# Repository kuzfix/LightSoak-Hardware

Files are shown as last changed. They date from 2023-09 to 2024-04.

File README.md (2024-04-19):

# LightSoak Hardware
This repository contains hardware design files for LightSoak project, developed in scope of my Master's thesis. For Firmware, quick start quide and a basic hardware description, see https://github.com/kuzfix/LightSoakFW-STM. For Python data logger, see https://github.com/kuzfix/LightSoakFW-Python.

LightSoak hardware can be used standalone via a Command Line Interface over USB or with a Python data logger to implement complex measurement sequences. See quick start quide at https://github.com/kuzfix/LightSoakFW-STM for more information.

## Hardware specs

### Voltage measurement channels
- Measurement range: **0-1.5V**
- ADC resolution: **12bit (STM32G4 integrated)**
- Sample rate: **100kHz**
- Differential input resistance: **3.3MOhm +- 10% (1GOhm +- 10% if input buffer board is used)**
- Noise performance: *TBD*. Use *getnoise* CLI command to evaluate.
    - *Note: Noise performance can be improved significantly by usage of the input buffer board*
- Over-range protection: **None**
- Accuracy: **+-(0.25% of measurement + 0.75mV)**

#### Voltage accuracy report
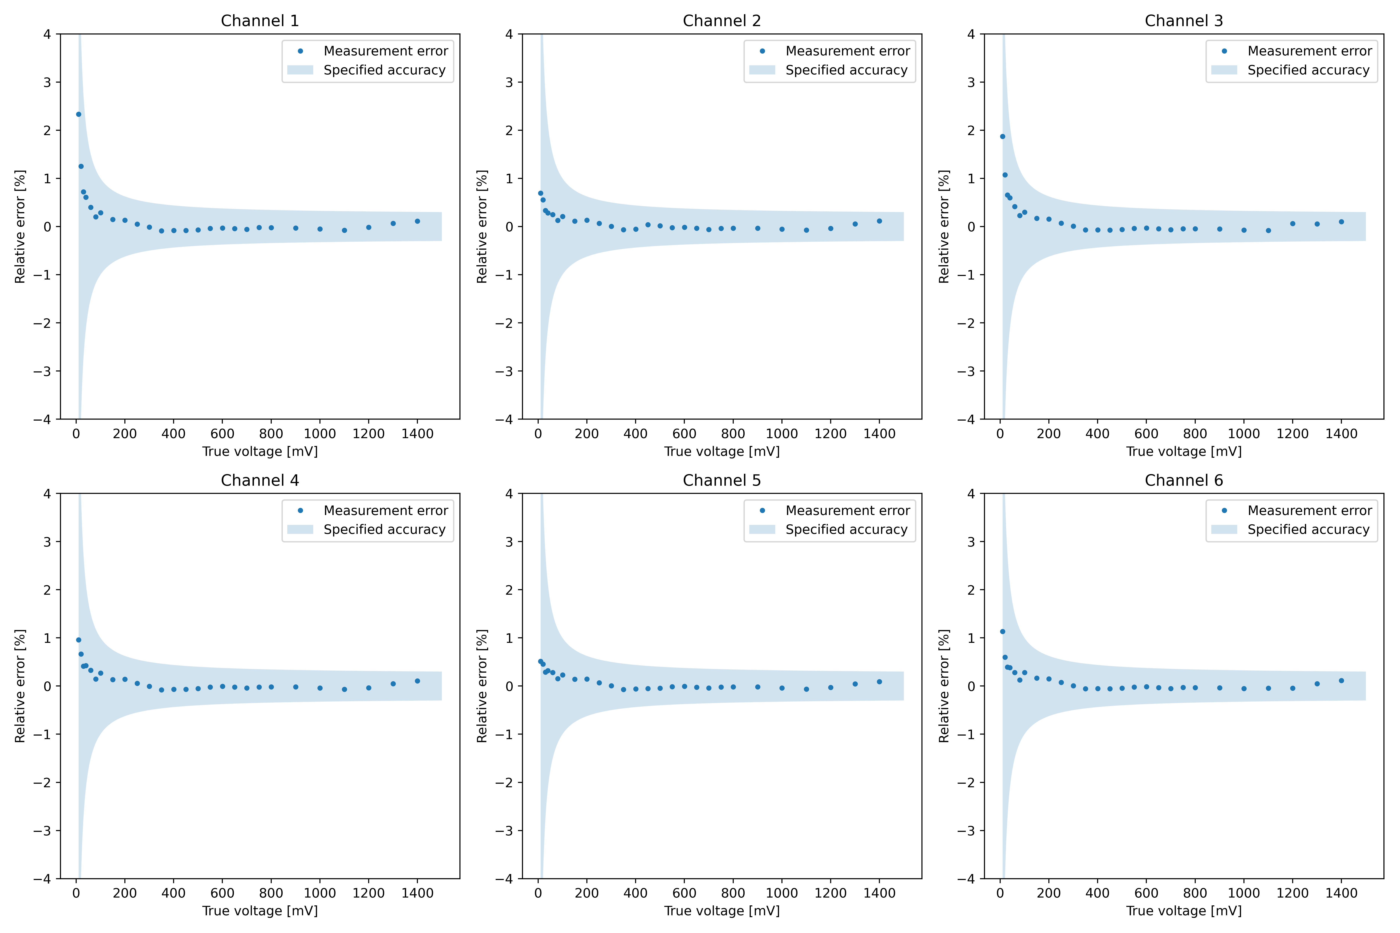
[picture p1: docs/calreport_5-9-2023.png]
Accuracy report:

- Calibration date: 5.9.2023
- Calibration equipment:
    - Keithly 237 (ULFE: 037296)
    - Agilent 34401A (ULFE: FE24)
- Sample averaging: 2000 (20ms averaging time)

### Current measurement channels
- Measurement ranges:
    - 1X: *up to 4700uA*
    - 10X: *up to 400uA*
    - 100X: *up to 40uA*
    - 1000X: *up to 4uA*
- ADC resolution: **12bit (STM32G4 integrated)**
- Sample rate: **100kHz** (simultaneous sampling with voltage channels)
- Noise performance: *TBD*. Use *getnoise* CLI command to evaluate.
- Over-range protection: **None**
- Accuracy: **+-(0.85% of measurement + 0.25uA)**
    - *Note: With shunt range optimization, higher accuracy can be reached. This is accuracy through the whole range including range switching.*
    - *Note: If the input buffer board is not used, voltage measurement circuitry loads the DUT with about 3.3Mohm. While measuring very small currents, this can cause a discrepancy between the measured and actual DUT current.

#### Current accuracy report
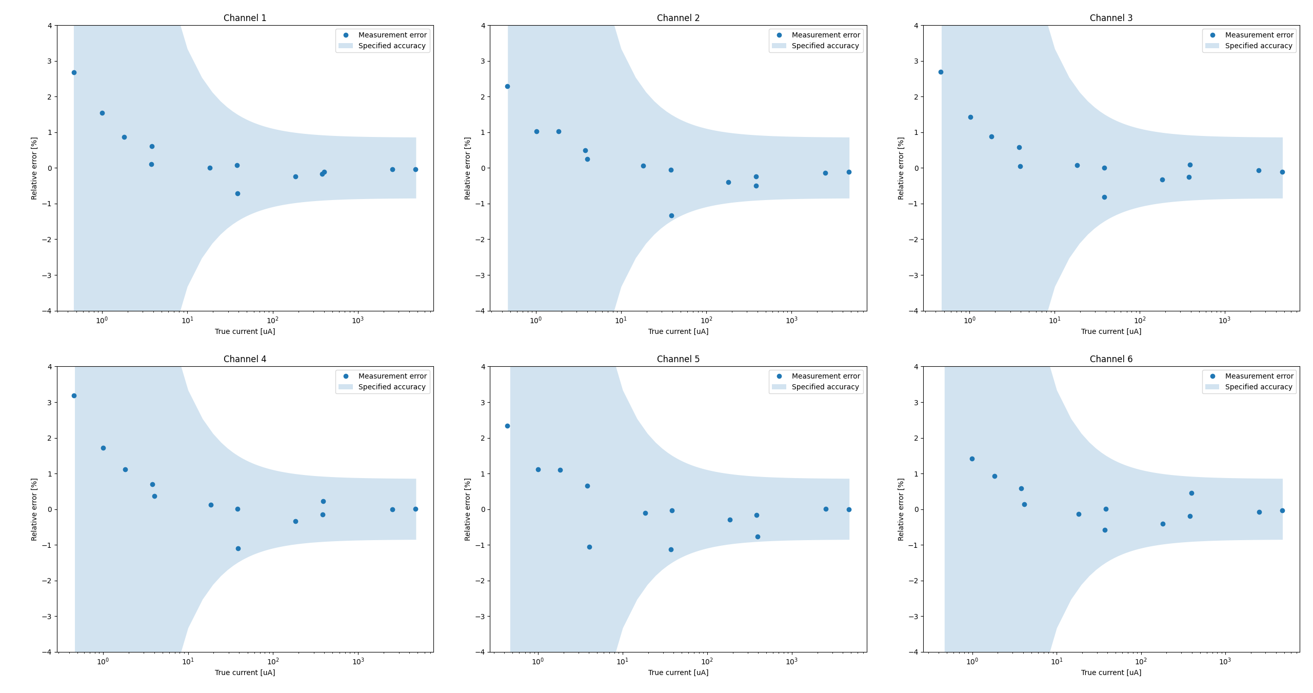
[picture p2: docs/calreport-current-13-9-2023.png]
Accuracy report:

- Calibration date: 13.9.2023
- Calibration equipment:
    - BM789
- Sample averaging: 2000 (20ms averaging time)

### Temperature control
- Handled by a TEC-1091 module mounted to the main board. See https://www.meerstetter.ch/products/tec-controllers/tec-1091 for specs.
- For continous max-power operation of temperature control, additional cooling is recomended for the power supply and TEC module section.

### Illumination
- Light output stbility: **+-1% (With LED temperature compensation)**
- Constant current range: **50mA to 1.4A**
    - *Note: Lower currents are possible with reduced transient performance*
- Settling time: **100uS to steady state, over current range**
    - *Note: Settling time is significantly shorter for higher currents. *
- 1 sun equivalent illumination (1000W/m^2): approximately 10 cm from LED at 1A (should be callibrated in-situ if accuracy is needed)
- See https://downloads.cree-led.com/files/ds/x/XLamp-CXA2530.pdf for LED specs
- Expected temperature rise of the heatsink is 10K at full power

### Power supply requirements
- **42V 2.5A DC** on input terminals to support all functionality.
- 5V 1A USB supply only (*VBUS-PWR* jumper installed): Analog functions work, performance may be degraded.

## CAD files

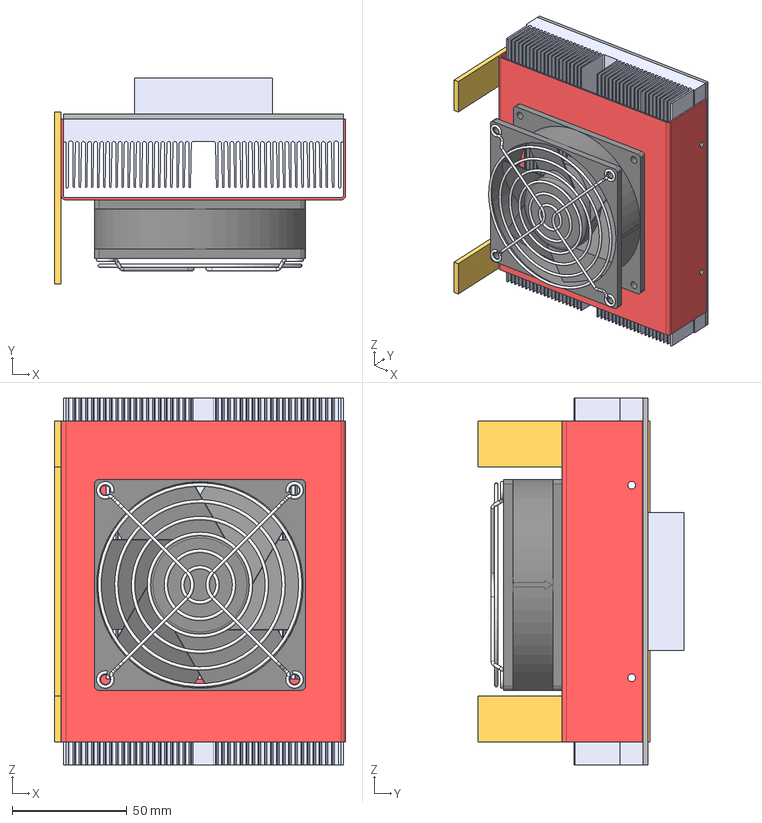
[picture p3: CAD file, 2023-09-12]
3D/mnt-bt-v2.step
127.0 x 89.6 x 160.0 mm

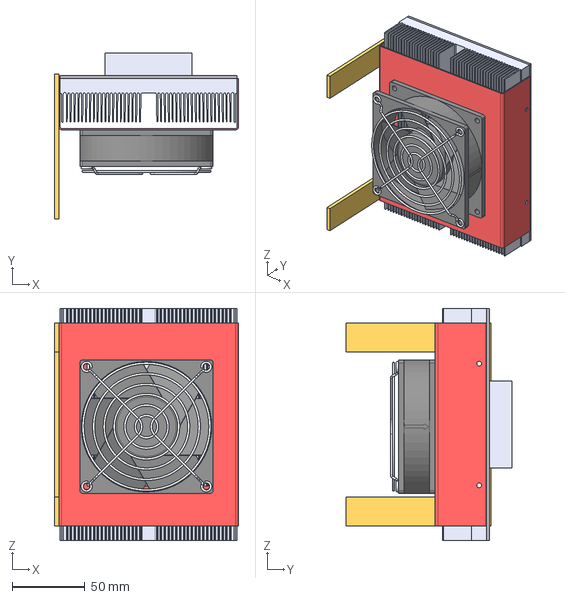
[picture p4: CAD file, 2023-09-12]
3D/mnt-btm-part-withfeet.step
127.0 x 114.6 x 160.0 mm

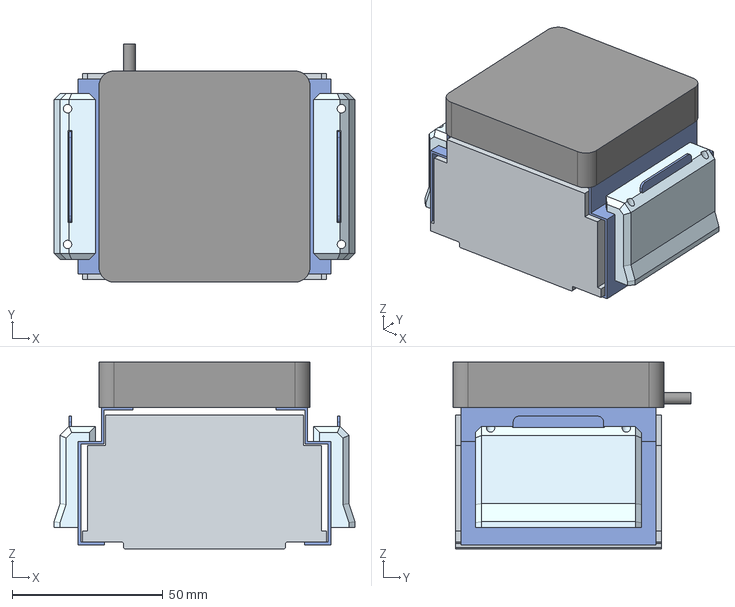
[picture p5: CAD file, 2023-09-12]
3D/LED-heatsink-withmnt.step
99.8 x 79.0 x 61.9 mm

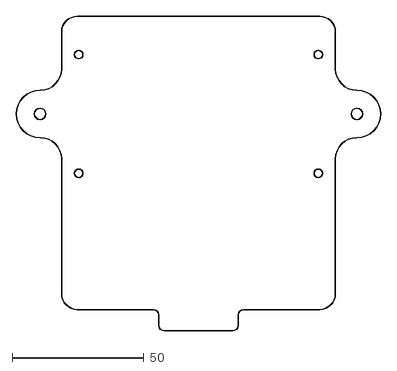
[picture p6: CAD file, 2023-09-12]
3D/LEDholder-pcb-shape-v1.dxf
138.0 x 119.2

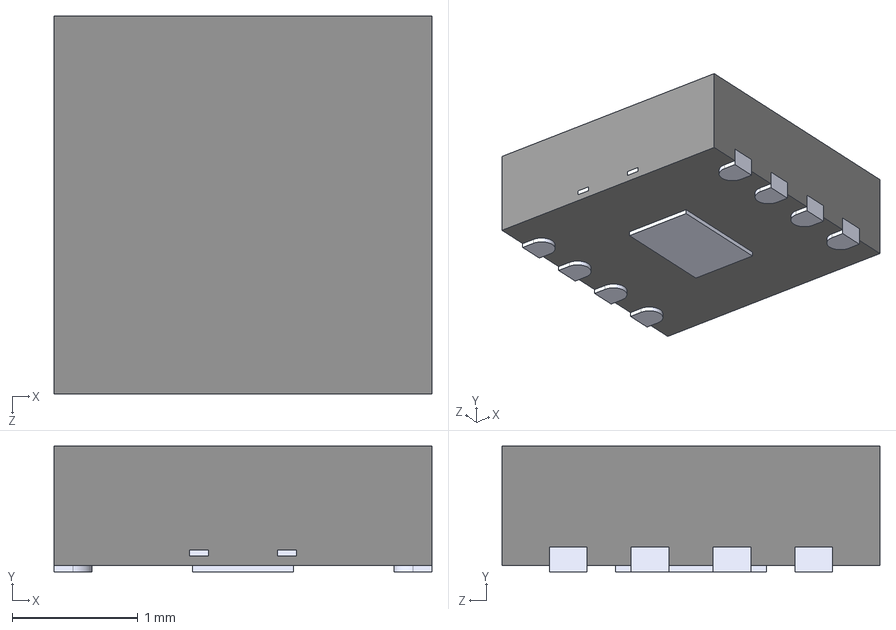
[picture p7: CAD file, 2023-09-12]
lightSoakV1-InAmp-piggyback/lightSoakV1-InAmp-piggyback/MCP14700-E_MF.STEP
3.00 x 1.00 x 3.00 mm

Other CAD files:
lightSoakV1-illumination/V1-PCB-illumination.DXF

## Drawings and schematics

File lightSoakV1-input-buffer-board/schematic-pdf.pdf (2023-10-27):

## Inline DUT unity gain buffer amplifier with extra high input impedance

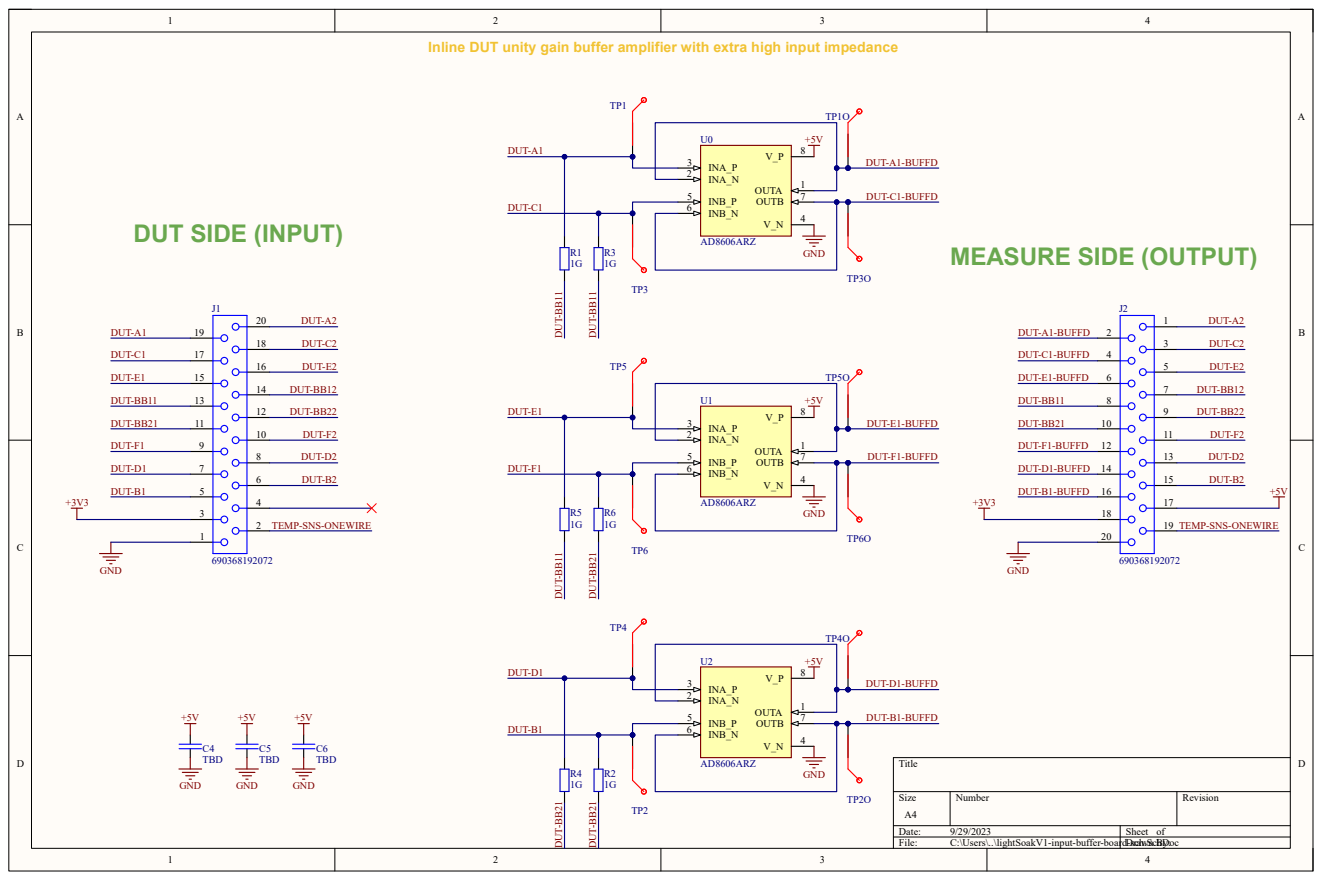
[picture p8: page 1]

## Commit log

2023-09-12 LED driver schematic modifications
    [V1_illuminationBoard_sch.SchDoc]
2023-09-13 added current accuracy report
2023-10-27 Annotation improvemets, buffer board design added, other changes.
    [lightSoakV1-input-buffer-board-pcb.PcbDoc, lightSoakV1-input-buffer-board-sch.SchDoc, lightSoakV1-input-buffer-board.PrjPcb]
